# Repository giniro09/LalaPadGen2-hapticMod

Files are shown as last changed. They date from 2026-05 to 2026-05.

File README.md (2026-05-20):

# LaLaPad Gen2 実験ビルドログ

このリポジトリは、LaLaPad Gen2 向けの個人的な ZMK カスタム実験の最新版スナップショットです。

- 公式の手順書ではありません
- 実験ログ / ビルドログとして公開しています
- 再現や流用は自己責任でお願いします
- 元プロジェクトの公式見解やサポート窓口ではありません

元の LaLaPad Gen2 プロジェクトおよび、そのベースとなる構成・発想に対して、敬意とクレジットを明記したうえで公開しています。

## このリポジトリの位置づけ

- 実験ビルドログ
- 現時点の既知の動作スナップショット
- LaLaPad Gen2 の公式リポジトリではない
- 元のプロジェクト管理者とは独立した、個人による下流カスタム実験

同じ改造を試したい場合は、以下の文書を参照してください。
- [配線・部品メモ](./docs/experiments/interaction-feedback/HARDWARE_AND_PIN_PLAN.md)
- [機構メモ](./docs/experiments/interaction-feedback/MECHANICAL_NOTES.md)
- [Force / Caret の現行仕様](./docs/experiments/interaction-feedback/CURRENT_FORCE_BEHAVIOR_SPEC.md)

## 3Dモデル

実験用に改造した3Dパーツは [`hardware/modified-parts/`](./hardware/modified-parts/) に置いています。

## ファームウェアに関する注意

このリポジトリには、私の個人試作機で使用しているファームウェア / 設定ファイルが含まれています。

ただし、これはあくまで実験中のスナップショットであり、他の環境での動作を保証するものではありません。  
ハードウェアの個体差、配線、部品、組み立て精度、ZMK環境などによって、動作しない、または異なる挙動になる可能性があります。

このファームウェアを書き込むことで、入力異常、誤動作、ハプティックの誤作動、バッテリー消費増加、その他の問題が発生する可能性があります。  
使用・改変・書き込みは自己責任でお願いします。

この実験ファームウェアおよびハードウェア改造について、元のLaLaPad Gen2制作者様・メンテナの方へサポート依頼を送らないでください。

## クレジット

LaLaPad Gen2 本体、元のプロジェクト構成、上流のファームウェア基盤については、元の制作者・管理者に帰属します。
- ShiniNet / LaLaPad Gen2
- 上流参照先は `config/west.yml` や関連文書に残しています

このリポジトリは、その上に個人的なカスタム実験を積み上げたものです。

## ライセンス

このスナップショットでは、リポジトリの `LICENSE` をそのまま維持しています。
上流側のライセンス条件を上書きする意図はありません。

派生物を公開する場合は、ライセンス表記を維持したうえで、`west` で取得する依存物のライセンスも各自で確認してください。

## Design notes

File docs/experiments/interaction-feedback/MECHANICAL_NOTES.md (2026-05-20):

# 機構メモ

この文書は、LaLaPad Gen2 haptic / force feedback 実験における現状の機構メモです。

正式な組み立て手順書ではありません。
あくまで、1つの試作機の実験ログとして共有します。

実験用に改造したパーツの3Dモデルは [`hardware/modified-parts/`](../../../hardware/modified-parts/) に置いていますが、現時点では、本来共有に足るレベルの出来ではありません。あくまで参考情報として扱ってください。
既製品パーツや配線については、 [HARDWARE_AND_PIN_PLAN.md](./HARDWARE_AND_PIN_PLAN.md) を参照してください。

---

## 構成概要

機構としては、下記画像の通り、キーボード片側につき3つのパーツを制作しています。
- 蓋1
- 蓋2
- FSR土台

トラックパッドセンサ基板裏に絶縁テープを貼る。意味があるかは不明。。私は4重くらいに貼ってます。
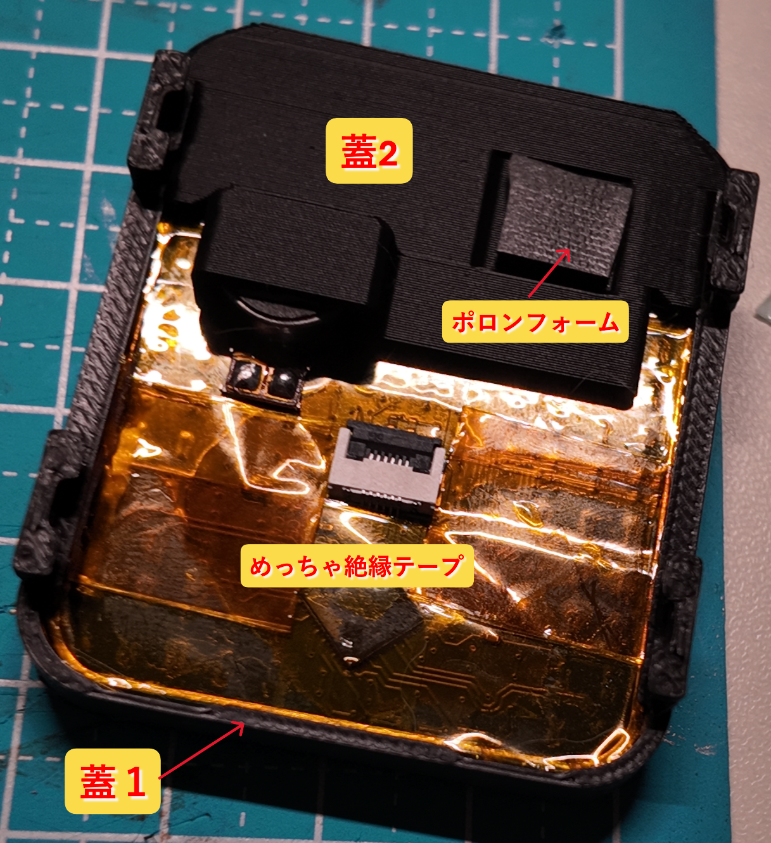
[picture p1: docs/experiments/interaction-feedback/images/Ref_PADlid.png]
PAD lid reference


ADS1115 をトラックパッド下の空間に配置、両面テープ固定。
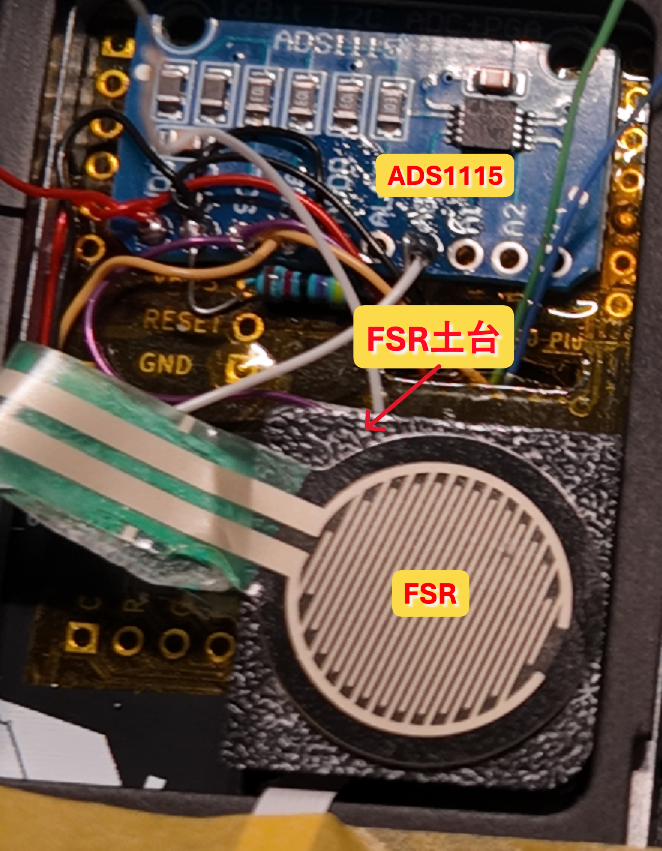
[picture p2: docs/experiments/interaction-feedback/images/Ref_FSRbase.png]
FSR base reference


DRV2605L は本体基板下の空間に配置、こちらも両面テープ固定しています。
DRV2605L placement

---

## 蓋1(pad-lid-1-hapticmod)

トラックパッドセンサ基板を挟むパーツ。
ベースモデルに対し、以下を実施しました。
- 臓物干渉避けのため、1mmの高さ延長
  - （別に延長いらなかったかもしれない）
- FSR押下用に、1mmのたわみスリット追加

スリットを追加したことによって、本体との地続き構造が細くなり、結果として振動が伝わりやすくなる効果も出ている、きっと。

下記画像は横から見た図です。

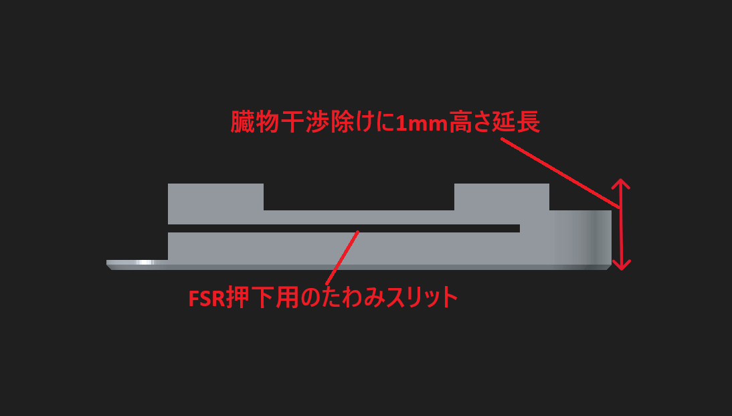
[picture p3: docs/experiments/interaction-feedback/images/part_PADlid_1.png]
PAD lid part 1


## 蓋2(pad-lid-2-hapticmod_L/R)

ベースモデルでは本来、蓋1にはめ込んでトラックパッドセンサ基板を固定するパーツ。
この改造では、腕不足によりはめ込み式ではなく、トラックパッドセンサ基板に両面テープで固定しています。

ベースモデルに対し、以下を実施しました。
- LRAをはめる場所を追加
- FSR押下用に、1mm薄く変更
- FSR押下用に、裏に PORON フォームを両面テープで接着

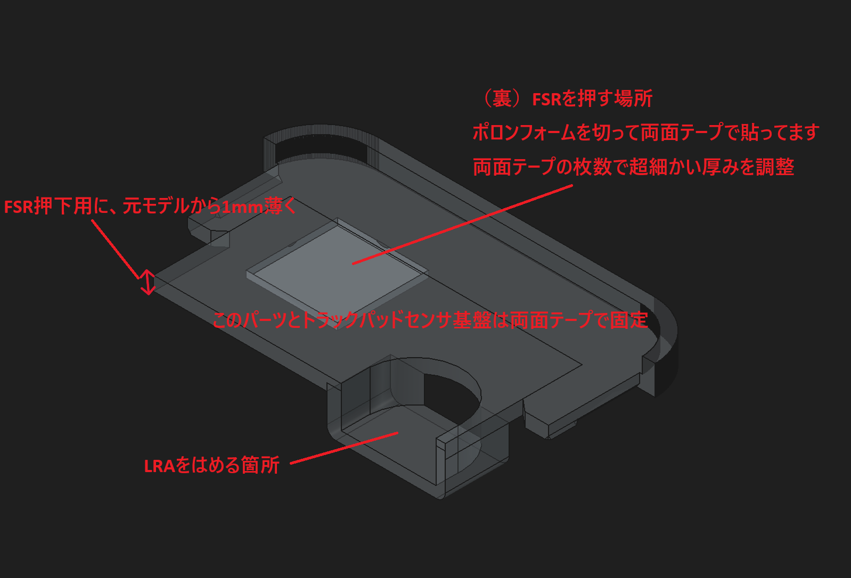
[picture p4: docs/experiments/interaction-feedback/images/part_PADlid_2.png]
PAD lid part 2


## FSRベース(fsr-base-hapticmod_L/R)

FSRベースに FSR を貼り付け、蓋2に接着した PORON フォームで押下することで圧力検知します。
ベース下部に隙間を設け、トラックパッド FFC やほかの配線が通るようにしています。
本体基板とは両面テープで固定しています。

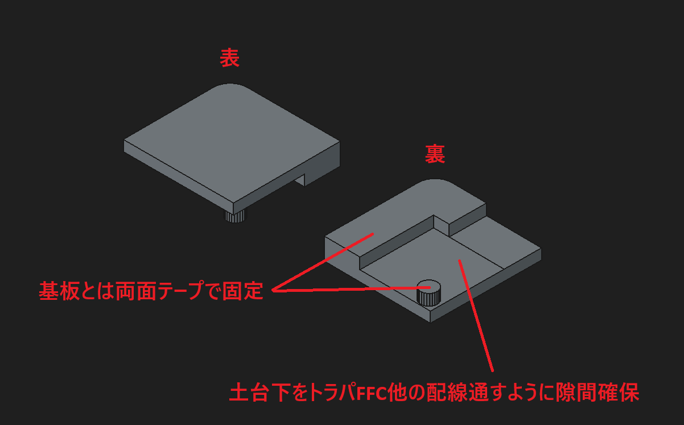
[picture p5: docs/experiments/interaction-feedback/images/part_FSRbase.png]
FSR base part


## 注意点

- 推測ですが、トラックパッド基板を強く押しすぎたり、たわませすぎたりすると、指の検知本数がおかしくなります。
  - コンマミリ単位での押下機構高さ調整により、それなりに安定するようになります。
  - 手元では FSR 押下用 PORON フォームを蓋2と接着する両面テープを重ね貼りしたりして調整しています。
- 操作感については、押下閾値 `FORCE_THRESHOLD` の調整や、プルダウン抵抗の抵抗値調整も有効です。

## 既知の課題・ほかメモ

- どれも素人仕事のためアレな出来ですが、特に蓋1に関しては多くの問題を抱えています。
  - 本体固定時の強度不足（普通に脚が折れたりします。）
  - たわみスリットがトラックパッド下部にしかないため、トラックパッド上部を押下できない・押下しても振動FBが感じづらい
  - 蓋2との固定機構が両面テープ
  - etc..
- FSR押下機構の調整が難しい。（左右同じように作っても、違う調整が必要だったり）
- LRA振動を最大限活かせていない。
  - 現状は操作面に対して鉛直方向の配置だが、水平方向振動の方が指先に感じやすい可能性。
  - 蓋1の脚や蓋2の固定機構も、振動伝達の観点でもっといいものがある筈。
- アナログ値で FSR 圧力を読めるようにしたものの、現時点ではあまり活かせていない。
- トラックパッドの本体取り付け時の配線の取り回し。FFCを変に巻き込まないように、FSRと押下面に挟まないように、、と気を遣う。

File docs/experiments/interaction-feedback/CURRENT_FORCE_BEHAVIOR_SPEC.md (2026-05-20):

# 現行 Force / Precision / Caret 仕様

この文書は、LaLaPad Gen2 haptic / force feedback 実験における現状の機能メモです。
キーマップ全体や通常ジェスチャの網羅は対象外とし、独自追加した Force / Precision / Caret と、その触覚フィードバックを中心に記載します。

## 用語

- **Force**: FSR の圧力を使って、通常のタップとは別系統で発火させる強押し入力。
- **Caret**: テキストカーソル移動を意図し、ポインタ移動の代わりに矢印キー入力へ切り替えるモード。
  一本指Forceをカーソル静止したまま一定時間入力すると遷移し、そのまま指を動かすと上下左右の矢印入力を行います。
- **Precision**: Force 中にポインタ速度を落として精密操作するためのモード。現状無効
- **FSR**: 押圧を電気信号として読むセンサ
- **LRA**: 触覚フィードバック用の振動子
  
## 現在の有効状態

- Force: 有効
- Caret: 有効。ただし IQS9151 driver 内のローカル Caret ではなく、`zmk,input-processor-force-caret` で中央処理する
- Precision: 無効。コードと設定値は残っているが、`CONFIG_INPUT_IQS9151_PRECISION_ENABLE=n`
- 通常 tap haptic: 無効
- 起動完了 haptic: 有効

左右どちらも FSR は ADS1115 経由で読み、Force 量は起動時/無接触時の idle 値からの距離として扱う。

## Force 閾値

`CONFIG_INPUT_IQS9151_FORCE_USE_ABSOLUTE=y` のため、Force 判定はタッチ開始時差分ではなく、idle 基準値からの絶対距離で見る。起動直後 `1500ms` は idle 値を学習し、その後も無接触かつ Force 非アクティブ中は idle 値をゆっくり追従させる。

| 側 / 指本数 | 進入閾値 | 解除閾値 |
| --- | ---: | ---: |
| 右 1本指 | `15000` | `9500` |
| 右 2本指 | `16000` | `10500` |
| 右 3本指 | `17000` | `11500` |
| 左 1本指 | `18000` | `11500` |
| 左 2本指 | `19000` | `12500` |
| 左 3本指 | `20000` | `13500` |

Force 進入デバウンスは `5ms`、解除デバウンスは `35ms`。Force release 後は `40ms` の再アーム待ちを置く。Force-owned hold drag 中は途中で途切れにくくするため、実効解除閾値を通常値の `3 / 4` に下げる。

## Force 出力

| 入力 | 現在の扱い |
| --- | --- |
| 1本指 Force | `INPUT_BTN_0` の Force-owned hold。静止が `450ms` 続くと hold を release して Caret に入る |
| 2本指 Force | `INPUT_BTN_0` の double click。Force-owned hold にはしない |
| 3本指 Force | `INPUT_BTN_5` の Force-owned hold。既存の 3F-up 仮想入力を使う |

2本指 Force は tap との差別化のため、右クリックではなくダブルクリック扱いにした。成立した瞬間に primary button click を2回送る。押しっぱなし右クリックや右ドラッグとしては扱わない。

3本指 Force は現時点では便利寄りの別機能枠として残している。実際の意味は `INPUT_BTN_5` の割り当て先に依存する。

## 触覚フィードバック

Force click 用の触覚フィードバックは DRV2605L の RTP mode で短い click 感を再生する。

- kick: `0x7F` を `2300us`
- brake: `0x88` を `1600us`
- zero: `0x00` を `600us`

2本指 Force は、1本指 Force と区別できるように同じ Force click haptic を短い間隔で2回鳴らす。「カカッ」というフィードバックを意図している。

通常 tap click の haptic は無効。tap は指を離す動作自体がフィードバックになるため、触覚フィードバックは Force / Caret / Caret 中の文字送りに寄せる。

起動完了時は、IQS9151 の初期化と IRQ 有効化が終わったタイミングで短い tick haptic を1回鳴らす。その側のトラックパッドが操作可能になったことを知らせる合図として扱う。

Haptic 再生直後は FSR への機械的な回り込みを避けるため、`25ms` の間は直前の安定値を使う。

## Caret

Caret は `zmk,input-processor-force-caret` が中央で処理する。左右のトラックパッド入力を共有状態で見るため、片側で Caret に入った後、反対側のトラックパッドでカーソル移動することもできる。

設定値:

- Caret 長押し時間: `450ms`
- Caret デッドゾーン: `80`
- Caret 候補の drag cancel 閾値: `18`

1本指 Force が静止文脈で成立すると、まず `INPUT_BTN_0` の Force-owned hold として扱う。そのまま `450ms` 続いた場合、中央 processor が primary hold を release し、Caret active に入る。

Caret 候補中に単発 REL 移動量が `18` 以上出た場合は、Caret 候補をキャンセルし、そのまま primary drag として扱う。小さなセンサー揺れだけでは Caret 候補を維持する。

Caret active 中は pointer REL_X / REL_Y を通常 pointer として出さず、蓄積量が `80` を超えるたびに `LEFT / RIGHT / UP / DOWN` のいずれかを1回 tap する。1イベントあたり最大4ステップまで出す。

Caret 時の触覚フィードバック:

- Caret に入る瞬間: Caret を成立させた側のトラックパッドで Force double click haptic
- Caret 中に1文字分カーソル移動した瞬間: 実際に移動入力を出した側のトラックパッドで cursor tick haptic

左右別 haptic は `zmk,behavior-iqs9151-haptic` で実行する。behavior 名は split 越しに送れるよう `ihl` / `ihr` の短い名前にしている。locality は `BEHAVIOR_LOCALITY_EVENT_SOURCE` とし、必要な側だけに送る。

## Precision

Precision は現在無効。

`zmk,input-processor-precision-scaler` と関連設定値は残っているが、driver 側で `precision_active` に入らないため実効しない。

残っている主な設定値:

- `CONFIG_ZMK_INPUT_PROCESSOR_PRECISION_SCALER_MAX_SCALE_X100=78`
- `CONFIG_ZMK_INPUT_PROCESSOR_PRECISION_SCALER_MIN_SCALE_X100=50`
- `CONFIG_ZMK_INPUT_PROCESSOR_PRECISION_SCALER_START_FORCE_DELTA=9000`
- `CONFIG_ZMK_INPUT_PROCESSOR_PRECISION_SCALER_MAX_FORCE_DELTA=12000`

## Tap / TapDrag との関係

Force が通常文脈で入ると、pending になっている tap click は clear され、1本指 tap 状態も reset される。Tap の遅延 click と Force 出力が二重に出ないようにするため。

TapDrag 中に Force threshold を超えた場合は `overlay_only` として扱う。現在は Precision が無効なので、Force 側が追加の pointer slowdown を与えることはない。既存 TapDrag の button ownership との競合を避ける処理は入っているが、この経路は実機確認が必要。

## 実機確認ポイント

- 1本指 Force が primary hold / drag として自然に使えること
- 1本指 Force 静止長押しで Caret に入り、入った側で「カカッ」と鳴ること
- Caret 中、左右どちらのトラックパッドで動かしても矢印入力になり、動かした側だけが tick すること
- 2本指 Force が primary double click として出て、「カカッ」と鳴ること
- 3本指 Force の割り当てが実使用上便利かどうか
- 通常 tap では haptic が鳴らないこと

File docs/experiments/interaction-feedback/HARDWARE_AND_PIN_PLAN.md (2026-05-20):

# 配線メモ

この文書は、 LaLaPad Gen2 haptic / force feedback 実験における既製品パーツ / 配線メモです。
## 使用部品

| 部品 |  個数 | 用途 | 製品 / 型番（※） | リンク | メモ |
| --- | --: | --- | --- | --- | --- |
| DRV2605L | 2 | LRA 駆動 | Adafruit DRV2605L Haptic Controller Breakout | [Digikey](https://www.digikey.jp/en/products/detail/adafruit-industries-llc/2305/5356831) | - |
| ADS1115  | 2 | FSR アナログ読み取り | ADS1115 モジュール | [Amazon](https://amzn.asia/d/0gqnW5av) | デジタル入力ではなくアナログで読んだが、結果論としてはデジタルで割り切って抵抗値調整だけで感度を詰める案もあるかも |
| LRA | 2 | 触覚フィードバック | Vybronics `VG1040003D` | [Digikey](https://www.digikey.jp/en/products/detail/vybronics-inc/VG1040003D/10285886) | 今回の用途に適した水平方向LRAがほかにあるかも？ |
| FSR | 2 | 押圧検知 | Interlink Electronics `30-81794` | [Digikey](https://www.digikey.jp/en/products/detail/interlink-electronics/30-81794/2476468) | もう少し脚の短いもののほうが扱いやすいかも |
| 抵抗 | 2 | FSR 分圧 | - | [Amazon](https://amzn.asia/d/0bPztfgd) | 現行メモでは FSR 分圧の固定抵抗は `47kΩ` |
| ポロンスポンジ  | - | 機構材 | - | [Amazon](https://amzn.asia/d/05BENvsO) | - |
| 細い電線 | - | 配線 | - | [Amazon](https://amzn.asia/d/0eE2hHJf) | - |
| 絶縁テープ | - | 絶縁 | - | [Amazon](https://amzn.asia/d/09UQO5TF) | - |
| 両面テープ | - | 固定 | - | [Amazon](https://amzn.asia/d/009edvbI) | - |
（※）製品/型番やリンクあくまで例。同等製品で代替可能のはずです。
## 補足
- これは再現性を保証する BOM ではありません！

## 片側キーボード分の実配線

以下は、左キーボード / 右キーボードどちらにも共通の1 台分の結線です。
### 配線メモ
- `DRV2605L VIN -> XIAO 3V3`
- `DRV2605L GND -> XIAO GND`
- `DRV2605L SDA/SCL -> XIAO D4/D5`
- `DRV2605L IN/TRIG -> 未接続（現行では未使用）`
- `DRV2605L OUT+ / OUT- -> LRA + / -`

- `ADS1115 VDD/GND -> XIAO 3V3/GND`
- `ADS1115 SDA/SCL -> XIAO D4/D5`
- `ADS1115 ADDR -> GND`（`0x48` 前提）
- `ADS1115 A0 -> FSR -`
- `ADS1115 A1/A2/A3 -> 未使用`

- `FSR + -> 3V3`
- `FSR - -> ADS1115 A0`
- `ADS1115 A0 -> 47kΩ 固定抵抗(※) -> GND`

- `LRA + -> DRV2605L OUT+`
- `LRA - -> DRV2605L OUT-`

補足:
- `FSR` 自体は極性部品ではないので、`+ / -` は便宜上の呼び方です
- 現行ファームは押し込みで `A0` 電圧が上がる向きの分圧を前提にしています
  (`CONFIG_INPUT_IQS9151_FORCE_INVERT_ANALOG=n`)
- (※)固定抵抗値は、私の手元環境で詰めた結果として`47kΩ`としていますが、調整可能です。

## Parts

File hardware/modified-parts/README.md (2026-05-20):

# 3D Models

This directory contains unofficial experimental modified 3D parts for my LaLaPad Gen2 haptic/force feedback prototype.

These parts are not official LaLaPad Gen2 parts.  
They are shared as experimental build-log materials only.

## Files

- `modified-parts/pad-lid-1-hapticmod.stl`
- `modified-parts/pad-lid-2-hapticmod_L.stl`
- `modified-parts/pad-lid-2-hapticmod_R.stl`
- `modified-parts/fsr-base-hapticmod_L.stl`
- `modified-parts/fsr-base-hapticmod_R.stl`

## Source Model Attribution

These modified parts are based on the original LaLaPad Gen2 Keyboard Case model.

Original model:

- Name: LaLaPad Gen2 Keyboard Case
- Creator: ShiniNet
- Source: https://makerworld.com/ja/models/2441156-lalapad-gen2-keyboard-case
- License: Creative Commons Attribution 4.0 International / CC BY 4.0
- License URL: https://creativecommons.org/licenses/by/4.0/

Changes made:

- Added/modified structures for the FSR load path
- Added/modified LRA placement
- Modified trackpad support parts for haptic/force feedback experimentation

These modified parts are unofficial derivative parts.  
They are not endorsed by the original creator.

## Disclaimer

- These parts are not production tested.
- Print tolerances may affect fit, preload, and FSR behavior.
- The mechanism may require manual adjustment.
- Reproducing this mod may damage your device.
- Use at your own risk.
- Please do not ask the original LaLaPad Gen2 creator/maintainer for support about these modified parts.

---

# 日本語補足

このフォルダには、LaLaPad Gen2 haptic/force feedback 実験用に改造した3Dパーツを置いています。

これは公式パーツではなく、個人試作機の実験ログとして共有しているものです。

## 元モデルのクレジット

この改造パーツは、ShiniNet氏による LaLaPad Gen2 Keyboard Case モデルをベースにしています。

- 元モデル: LaLaPad Gen2 Keyboard Case
- 制作者: ShiniNet
- 配布元: https://makerworld.com/ja/models/2441156-lalapad-gen2-keyboard-case
- ライセンス: Creative Commons Attribution 4.0 International / CC BY 4.0
- ライセンスURL: https://creativecommons.org/licenses/by/4.0/

変更内容:

- FSR荷重経路用の構造追加/変更
- LRA配置用の構造追加/変更
- haptic/force feedback実験用のトラックパッド支持部品変更

これらは非公式の個人実験用改造パーツであり、公式のLaLaPad Gen2部品ではありません。  
元制作者による公認・保証・推奨を示すものではありません。

## 注意

- 量産検証済みではありません
- プリンタや素材によって寸法調整が必要です
- FSRの押下量やプリロードは組み立て状態に強く依存します
- 取り付けにより本体を破損する可能性があります
- 再現は自己責任でお願いします
- この改造パーツについて、元制作者の方へサポート依頼を送らないでください

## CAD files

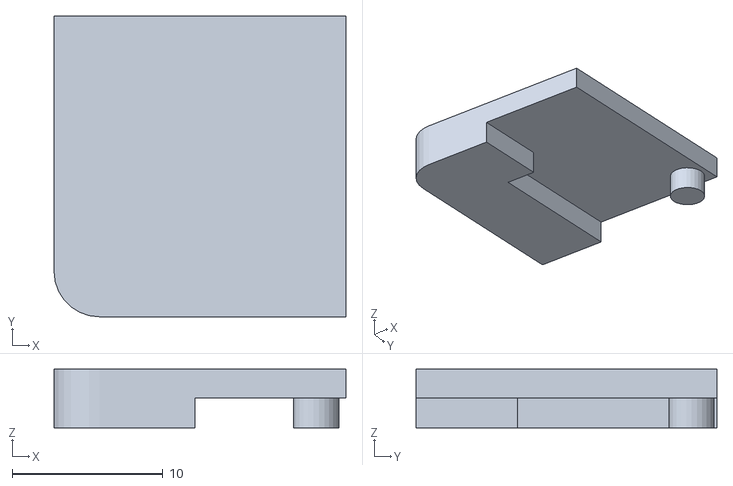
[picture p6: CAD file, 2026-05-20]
hardware/modified-parts/fsr-base-hapticmod_R.stl
19.4 x 19.9 x 3.91

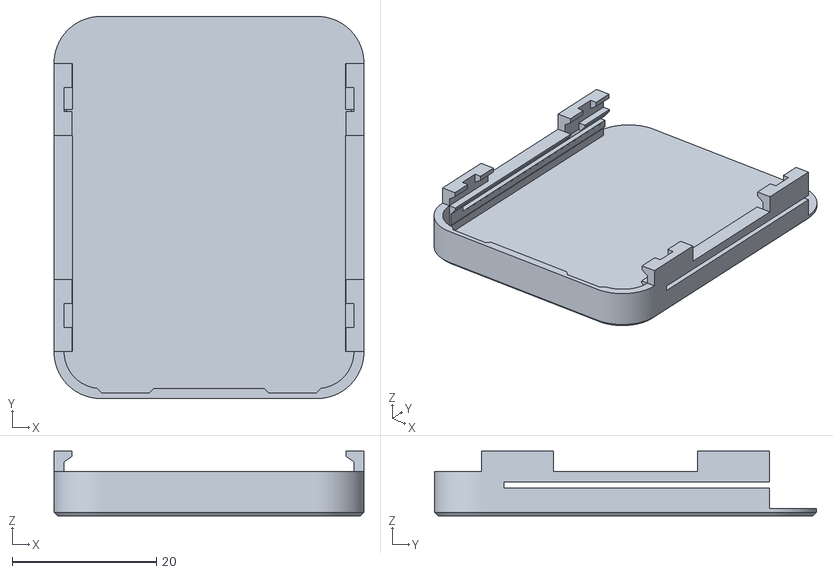
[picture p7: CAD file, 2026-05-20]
hardware/modified-parts/pad-lid-1-hapticmod.stl
43.0 x 53.0 x 9.00

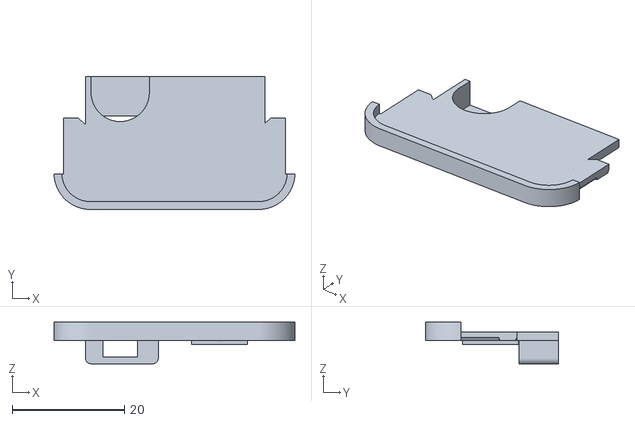
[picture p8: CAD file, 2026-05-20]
hardware/modified-parts/pad-lid-2-hapticmod_L.stl
43.0 x 23.7 x 7.42

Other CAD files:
hardware/modified-parts/fsr-base-hapticmod_L.stl
hardware/modified-parts/pad-lid-2-hapticmod_R.stl
